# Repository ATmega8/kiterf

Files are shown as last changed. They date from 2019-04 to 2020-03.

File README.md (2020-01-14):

# _KiteRF_





_KiteRF is a SDR system with K210 & FPGA & ESP32 as its core controller, which make SDR more intelligent, portable and cheap._

* KiteRF Structure

  KiteRF

  * DS (Digital Signal) unit

    * FPGA (Field-Programmable Gate Array)

      * Radio Frequency Data Processing

      * DS Control

      * Communication with PC

    * K210 (Kendryte K210)

      * LCD control

      * Camera control

      * Audio

      * FFT

    * ESP32 (Espressif ESP32)

      * Wi-Fi Data Transmission

      * SDCARD control

      * Touch Button

      * RGB LED Control

  * RF (Radio Frequency) unit

    * ADC (Analog-to-Digital Converter)
    
      * Sampling Analog Baseband IQ Data

    * DAC (Digital-to-Analog Converter)

      * Output Analog Baseband IQ Data 

    * RF Transceiver

      * Mixing IF signal to baseband and outputting IQ analog signal

    * VCO (Voltage-Controlled Oscillator)

      * Provide local IF frequency

    * Mixer (Frequency mixer)

      * Mixing HF signal to IF signal

    * LNA (Low-Noise Amplifier)

      * Suppression of Mirror Noise Signal

    * RF Switch

      * Switching signal paths in different frequencies

* KiteRF core-board v1.0.0

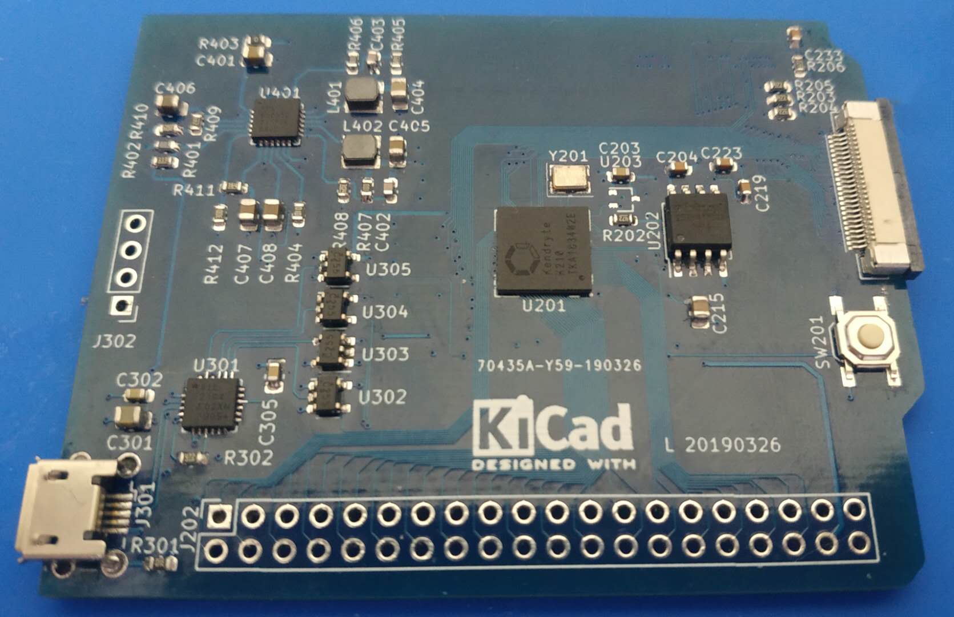
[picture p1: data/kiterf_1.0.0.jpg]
KiteRF
  

## Contents



* Directory tree

    ```
    ├── add_path.sh
    ├── data
    │   ├── kendryte_datasheet.pdf
    │   ├── kendryte_freertos_programming_guide.pdf
    │   ├── kiterf_1.0.0.jpg
    │   ├── kiterf_structure.pos
    │   └── kiterf_structure.svg
    ├── docs
    │   └── Doxyfile
    ├── LICENSE
    ├── project
    │   ├── code
    │   │   ├── ESP32
    │   │   ├── ESP8266
    │   │   └── K210
    │   └── pcb
    │       ├── K210
    │       └── RF
    ├── README.md
    └── tools
        ├── cmake-3.14.2
        ├── ESP32
        │   └── esp-idf
        ├── ESP8266
        │   ├── ESP8266_RTOS_SDK
        │   └── xtensa-lx106-elf
        └── K210
            ├── kendryte-freertos-sdk
            ├── kendryte-toolchain
            └── kflash
    ```

    * project

      * PCB project (KiCAD)

      * FPGA project (ISE)

      * ESP32 project (esp-idf)

      * K210 project (Kendryte FreeRTOS)

    * release

      * PCB Gerber

      * FPGA bin

      * ESP32 bin

      * K210 bin

    * tools

      * script

      * SDK

      * toolchain

## How to use

You can follow the steps below to set up the development environment, or directly download the release version of the full environment.

* clone

  ```bash
  git clone --recursive https://github.com/ATmega8/kiterf
  cd kiterf
  ```

  * note

    Don't omit `--recursive`, because we use submodule.

* update

  ```bash
  git pull
  git submodule update --init --recursive
  ```

* Add environment variables

  ```bash
  . add_path.sh
  ```
  * note

    Don't forget `"."`

* Install toolchain

  * K210

    * Ubuntu/Debian/Kali

      ```bash
      wget https://www.kiterf.xyz/download/kendryte-toolchain-ubuntu-amd64-8.2.0-20190213.tar.gz
      tar zxvf kendryte-toolchain-ubuntu-amd64-8.2.0-20190213.tar.gz -C tools/K210/
      rm kendryte-toolchain-ubuntu-amd64-8.2.0-20190213.tar.gz
      ```
    
    * Arch

      ```bash
      wget https://www.kiterf.xyz/download/kendryte-toolchain-arch-amd64-8.2.0-20190415.tar.gz
      tar zxvf kendryte-toolchain-arch-amd64-8.2.0-20190415.tar.gz -C tools/K210/
      rm kendryte-toolchain-arch-amd64-8.2.0-20190415.tar.gz
      ```

  * ESP32

    * Ubuntu/Debian/Kali/Arch

      ```bash
      cd tools/ESP32/esp-idf
      ./install.sh
      cd $KITERF_PATH
      ```

  * ESP8266

    KiteRF also integrates the ESP8266 development environment, which is not necessary, and you can choose to ignore it.

    * Ubuntu/Debian/Kali/Arch

      ```bash
      wget https://www.kiterf.xyz/download/xtensa-lx106-elf-linux64-1.22.0-92-g8facf4c-5.2.0.tar.gz
      tar zxvf xtensa-lx106-elf-linux64-1.22.0-92-g8facf4c-5.2.0.tar.gz -C tools/ESP8266/
      rm xtensa-lx106-elf-linux64-1.22.0-92-g8facf4c-5.2.0.tar.gz
      ```

  * CMake

    * Ubuntu/Debian/Kali/Arch

      ```bash
      wget https://www.kiterf.xyz/download/cmake-3.14.2.tar.gz
      tar xf cmake-3.14.2.tar.gz -C tools/
      cd tools/cmake-3.14.2
      ./configure
      # Please do not use all CPU cores to compile, otherwise your computer may crash.
      make -j2
      cd $KITERF_PATH
      rm cmake-3.14.2.tar.gz
      ```

## Release

* download

  ```bash
  wget https://www.kiterf.xyz/download/kiterf-debain-amd64-1.2.0-20190517.tar.gz
  tar zxvf kiterf-debain-amd64-1.2.0-20190517.tar.gz
  rm kiterf-debain-amd64-1.2.0-20190517.tar.gz
  cd kiterf
  ```
* Add environment variables

  ```bash
  . add_path.sh
  ```
  * note

    Don't forget `"."`

## License



* MIT License
 
  A short and simple permissive license with conditions only requiring preservation of copyright and license notices. Licensed works, modifications, and larger works may be distributed under different terms and without source code.

## Contributing



If you want to support this project, we hope you can contribute your code or circuit.

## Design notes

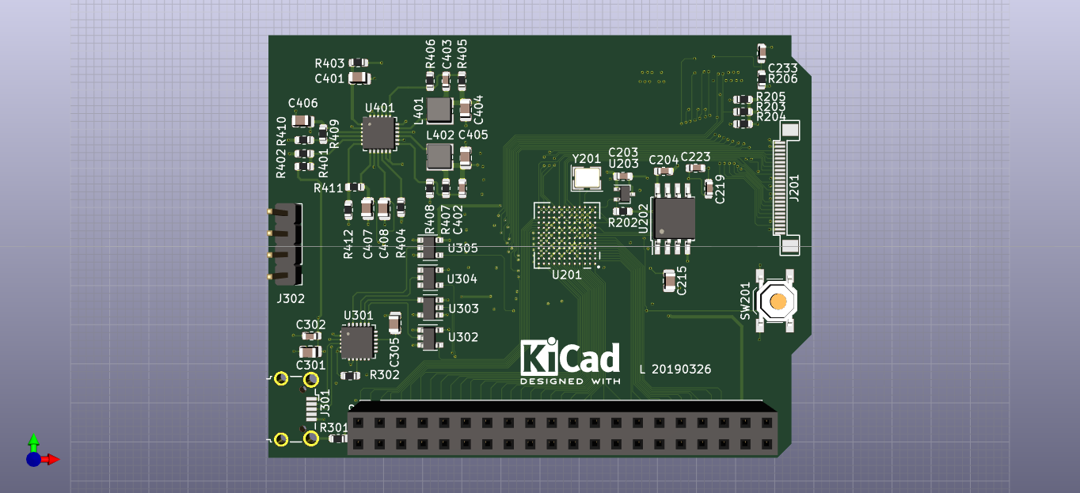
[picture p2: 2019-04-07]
project/pcb/K210/ESP32_K210.png

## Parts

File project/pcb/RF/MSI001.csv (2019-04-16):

Source: | /home/life/Code/kiterf/project/pcb/RF/MSI001.sch
Date: | 2019年04月16日 星期二 14时15分33秒
Tool: | Eeschema 5.1.0
Generator: | /usr/share/kicad/plugins/bom_csv_grouped_by_value_with_fp.py
Component Count: | 170
Ref | Qnty | Value | Cmp name | Footprint | Description | Vendor
C205, C206, C207, C208, C210, C212, C209, C211, C217, C215, C204, C202, C213, C214, C303, C313, | 16 | 0.1uF | C | Capacitor_SMD:C_0603_1608Metric | Unpolarized capacitor
C216, C203, C201, C508, C507, C503, C505, C509, | 8 | 10uF | C | Capacitor_SMD:C_0805_2012Metric | Unpolarized capacitor
C304, C306, | 2 | 100pF | C | Capacitor_SMD:C_0603_1608Metric | Unpolarized capacitor
C310, C326, | 2 | 3.3pF | C | Capacitor_SMD:C_0603_1608Metric | Unpolarized capacitor
C311, C302, | 2 | 120pF | C | Capacitor_SMD:C_0603_1608Metric | Unpolarized capacitor
C312, C322, C323, C324, | 4 | 1000pF | C | Capacitor_SMD:C_0603_1608Metric | Unpolarized capacitor
C314, | 1 | 82pF | C | Capacitor_SMD:C_0603_1608Metric | Unpolarized capacitor
C315, C328, | 2 | 2.7pF | C | Capacitor_SMD:C_0603_1608Metric | Unpolarized capacitor
C320, | 1 | 180pF | C | Capacitor_SMD:C_0603_1608Metric | Unpolarized capacitor
C321, | 1 | 3.9pF | C | Capacitor_SMD:C_0603_1608Metric | Unpolarized capacitor
C327, | 1 | 12pF | C | Capacitor_SMD:C_0603_1608Metric | Unpolarized capacitor
C402, C404, C401, C403, | 4 | 5.6pF | C | Capacitor_SMD:C_0603_1608Metric | Unpolarized capacitor
C405, C329, | 2 | 4.7pF | C | Capacitor_SMD:C_0603_1608Metric | Unpolarized capacitor
C406, C408, | 2 | 27pF | C | Capacitor_SMD:C_0603_1608Metric | Unpolarized capacitor
C409, C420, | 2 | 10pF | C | Capacitor_SMD:C_0603_1608Metric | Unpolarized capacitor
C410, C501, C502, | 3 | 22pF | C | Capacitor_SMD:C_0603_1608Metric | Unpolarized capacitor
C411, | 1 | 1nF | C | Capacitor_SMD:C_0603_1608Metric | Unpolarized capacitor
C412, C416, C407, | 3 | 1.8pF | C | Capacitor_SMD:C_0603_1608Metric | Unpolarized capacitor
C414, C316, C325, C301, | 4 | 39pF | C | Capacitor_SMD:C_0603_1608Metric | Unpolarized capacitor
C415, C419, C423, C424, C425, C422, C421, C429, C433, C436, C430, C428, C431, C432, C504, C506, C307, C305, C309, C308, C332, C330, C331, C318, C319, C317, | 26 | 10nF | C | Capacitor_SMD:C_0603_1608Metric | Unpolarized capacitor
C417, | 1 | 2.2pF | C | Capacitor_SMD:C_0603_1608Metric | Unpolarized capacitor
C418, C413, | 2 | 1.5pF | C | Capacitor_SMD:C_0603_1608Metric | Unpolarized capacitor
C426, C427, | 2 | 100nF | C | Capacitor_SMD:C_0603_1608Metric | Unpolarized capacitor
C434, | 1 | 6800pF | C | Capacitor_SMD:C_0603_1608Metric | Unpolarized capacitor
C435, | 1 | 33nF | C | Capacitor_SMD:C_0603_1608Metric | Unpolarized capacitor
C511, C510, C512, | 3 | 1uF | C | Capacitor_SMD:C_0805_2012Metric | Unpolarized capacitor
FB502, FB501, FB503, | 3 | Ferrite_Bead | Ferrite_Bead | Inductor_SMD:L_0805_2012Metric | Ferrite bead
J101, | 1 | CONTROL | Conn_02x08_Odd_Even | Connector_PinSocket_2.54mm:PinSocket_2x08_P2.54mm_Vertical | Generic connector, double row, 02x08, odd/even pin numbering scheme (row 1 odd numbers, row 2 even numbers), script generated (kicad-library-utils/schlib/autogen/connector/)
J201, | 1 | Conn_02x12_Odd_Even | Conn_02x12_Odd_Even | Connector_PinSocket_2.54mm:PinSocket_2x12_P2.54mm_Vertical | Generic connector, double row, 02x12, odd/even pin numbering scheme (row 1 odd numbers, row 2 even numbers), script generated (kicad-library-utils/schlib/autogen/connector/)
J301, | 1 | ANT | Conn_Coaxial | Connector_Coaxial:SMA_Amphenol_132289_EdgeMount | coaxial connector (BNC, SMA, SMB, SMC, Cinch/RCA, ...)
J501, | 1 | +5V | Conn_01x02_Female | Connector_PinSocket_2.54mm:PinSocket_1x02_P2.54mm_Vertical | Generic connector, single row, 01x02, script generated (kicad-library-utils/schlib/autogen/connector/)
JP201, | 1 | Jumper_NC_Dual | Jumper_NC_Dual | Jumper:SolderJumper-3_P1.3mm_Open_Pad1.0x1.5mm | Dual jumper, normally closed
JP202, | 1 | SolderJumper_3_Open | SolderJumper_3_Open | Jumper:SolderJumper-3_P1.3mm_Open_RoundedPad1.0x1.5mm | Solder Jumper, 3-pole, open
L301, | 1 | 150nH | L | Inductor_SMD:L_0603_1608Metric | Inductor
L302, | 1 | 390nH | L | Inductor_SMD:L_0603_1608Metric | Inductor
L303, | 1 | 1uH | L | Inductor_SMD:L_0603_1608Metric | Inductor
L304, L307, | 2 | 330nH | L | Inductor_SMD:L_0603_1608Metric | Inductor
L305, | 1 | 470nH | L | Inductor_SMD:L_0603_1608Metric | Inductor
L306, | 1 | 220nH | L | Inductor_SMD:L_0603_1608Metric | Inductor
L309, | 1 | 120nH | L | Inductor_SMD:L_0603_1608Metric | Inductor
L401, L310, | 2 | 82nH | L | Inductor_SMD:L_0603_1608Metric | Inductor
L402, | 1 | 15nH | L | Inductor_SMD:L_0603_1608Metric | Inductor
L403, | 1 | 68nH | L | Inductor_SMD:L_0603_1608Metric | Inductor
L404, | 1 | 22nH | L | Inductor_SMD:L_0603_1608Metric | Inductor
L405, | 1 | 33nH | L | Inductor_SMD:L_0603_1608Metric | Inductor
L407, | 1 | 39nH | L | Inductor_SMD:L_0603_1608Metric | Inductor
L408, | 1 | 6.8pF | L | Inductor_SMD:L_0603_1608Metric | Inductor
L409, | 1 | 6.8nH | L | Inductor_SMD:L_0603_1608Metric | Inductor
L410, L308, | 2 | 47nH | L | Inductor_SMD:L_0603_1608Metric | Inductor
L411, L406, | 2 | 100nH | L | Inductor_SMD:L_0603_1608Metric | Inductor
L412, | 1 | 270nH | L | Inductor_SMD:L_0603_1608Metric | Inductor
L413, | 1 | 8.2nH | L | Inductor_SMD:L_0603_1608Metric | Inductor
Q301, Q302, | 2 | DMG1016 | Q_PMOS_DGS | Package_TO_SOT_SMD:SOT-23 | P-MOSFET transistor, drain/gate/source
R202, R203, R204, R201, | 4 | 36R | R | Resistor_SMD:R_0603_1608Metric | Resistor
R205, R206, R207, R208, R209, R210, R506, R504, R505, R503, | 10 | 0R | R | Resistor_SMD:R_0603_1608Metric | Resistor
R301, | 1 | 270R | R | Resistor_SMD:R_0603_1608Metric | Resistor
R302, | 1 | 100K | R | Resistor_SMD:R_0603_1608Metric | Resistor
R402, R406, R401, R405, | 4 | 33R | R | Resistor_SMD:R_0603_1608Metric | Resistor
R404, R403, | 2 | 18R | R | Resistor_SMD:R_0603_1608Metric | Resistor
R407, | 1 | 390 | R | Resistor_SMD:R_0603_1608Metric | Resistor
R502, R501, | 2 | 10K | R | Resistor_SMD:R_0603_1608Metric | Resistor
U202, U201, | 2 | 74LVC1G125 | 74LVC1G125 | Package_TO_SOT_SMD:SOT-23-5 | Single Buffer Gate Tri-State, Low-Voltage CMOS
U203, | 1 | AD9288 | AD9288 | Package_QFP:LQFP-48_7x7mm_P0.5mm
U301, U305, | 2 | PE42641 | PE42641 | Package_DFN_QFN:QFN-16-1EP_3x3mm_P0.5mm_EP1.7x1.7mm
U302, | 1 | MGA68563 | MGA68563 | Package_TO_SOT_SMD:SOT-363_SC-70-6
U303, | 1 | 74LVC1G08 | 74LVC1G08 | Package_TO_SOT_SMD:SOT-23-5 | Single AND Gate, Low-Voltage CMOS
U304, | 1 | SKY13251 | SKY13251 | Package_DFN_QFN:DFN-8-1EP_2x2mm_P0.5mm_EP0.9x1.3mm
U401, | 1 | MSI001 | MSI001 | Package_DFN_QFN:QFN-40-1EP_6x6mm_P0.5mm_EP4.6x4.6mm_ThermalVias
U501, | 1 | SI5351A | SI5351A | Package_SO:MSOP-10_3x3mm_P0.5mm
U503, U502, | 2 | LP5907MFX-3.3 | LP5907MFX-2.8 | Package_TO_SOT_SMD:SOT-23-5 | 250-mA Ultra-Low-Noise Low-IQ LDO, 2.8V, SOT-23
U504, | 1 | LP5907MFX-2.8 | LP5907MFX-2.8 | Package_TO_SOT_SMD:SOT-23-5 | 250-mA Ultra-Low-Noise Low-IQ LDO, 2.8V, SOT-23
Y501, | 1 | 25MHz 10ppm | Crystal_GND24_Small | Crystal:Crystal_SMD_3225-4Pin_3.2x2.5mm | Four pin crystal, GND on pins 2 and 4, small symbol

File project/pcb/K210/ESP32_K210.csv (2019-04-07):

Source: | /home/life/KICAD/ESP32_K210/ESP32_K210.sch
Date: | 2019年03月26日 星期二 02时06分47秒
Tool: | Eeschema 5.1.0
Generator: | /usr/share/kicad/plugins/bom_csv_grouped_by_value_with_fp.py
Component Count: | 90
Ref | Qnty | Value | Cmp name | Footprint | Description | Vendor
C201, C202, | 2 | 10p | C | Capacitor_SMD:C_0603_1608Metric | Unpolarized capacitor
C204, C203, C229, C232, C206, C207, C209, C210, C211, C212, C213, C216, C217, C218, C219, C221, C223, C225, C227, C224, C226, C228, | 22 | 0.1uF | C | Capacitor_SMD:C_0603_1608Metric | Unpolarized capacitor
C205, C208, C215, C214, C222, C220, C303, C305, C301, | 9 | 4.7uF | C-SmartRelay-rescue | Capacitor_SMD:C_0805_2012Metric
C230, C231, | 2 | 4.7uF | C | Capacitor_SMD:C_0603_1608Metric | Unpolarized capacitor
C233, | 1 | 1uF | C | Capacitor_SMD:C_0603_1608Metric | Unpolarized capacitor
C304, C302, | 2 | 0.1u | C-SmartRelay-rescue | Capacitor_SMD:C_0603_1608Metric
C401, | 1 | 1u | C | Capacitor_SMD:C_0805_2012Metric | Unpolarized capacitor
C403, C402, | 2 | 47p | C | Capacitor_SMD:C_0603_1608Metric | Unpolarized capacitor
C404, | 1 | 10u | C | Capacitor_SMD:C_0805_2012Metric | Unpolarized capacitor
C405, | 1 | 10uF | C | Capacitor_SMD:C_0805_2012Metric | Unpolarized capacitor
C406, C407, C408, | 3 | 4.7u | C | Capacitor_SMD:C_0805_2012Metric | Unpolarized capacitor
FB203, FB201, FB202, | 3 | 600R@100MHz | Ferrite_Bead_Small | Inductor_SMD:L_0805_2012Metric | Ferrite bead, small symbol
J201, | 1 | Camera | Conn_01x24 | FPC:FPC_24 | Generic connector, single row, 01x24, script generated (kicad-library-utils/schlib/autogen/connector/)
J202, | 1 | Conn_02x20_Odd_Even | Conn_02x20_Odd_Even | Connector_PinSocket_2.54mm:PinSocket_2x20_P2.54mm_Vertical | Generic connector, double row, 02x20, odd/even pin numbering scheme (row 1 odd numbers, row 2 even numbers), script generated (kicad-library-utils/schlib/autogen/connector/)
J203, | 1 | LCD | Conn_2Rows-45Pins | FPC:FH26-xxS-0.3SHW | Generic connector, double row, 45 pins, odd/even pin numbering scheme (row 1 odd numbers, row 2 even numbers), script generated (kicad-library-utils/schlib/autogen/connector/)
J301, | 1 | USB_OTG | USB_OTG-SmartRelay-rescue | Connector_USB:USB_Micro-B_Wuerth_629105150521_CircularHoles
J302, | 1 | Conn_01x04 | Conn_01x04-SmartRelay-rescue | Connector_PinHeader_2.54mm:PinHeader_1x04_P2.54mm_Vertical
JP201, | 1 | IO18-IO35 | SolderJumper_3_Open | Jumper:SolderJumper-3_P1.3mm_Open_RoundedPad1.0x1.5mm | Solder Jumper, 3-pole, open
JP202, | 1 | IO0-IO17 | SolderJumper_3_Open | Jumper:SolderJumper-3_P1.3mm_Open_RoundedPad1.0x1.5mm | Solder Jumper, 3-pole, open
JP203, | 1 | IO36-IO47 | SolderJumper_3_Open | Jumper:SolderJumper-3_P1.3mm_Open_RoundedPad1.0x1.5mm | Solder Jumper, 3-pole, open
L401, | 1 | 3.3uH | L | Inductor_SMD:L_Wuerth_MAPI-3015 | Inductor
L402, | 1 | 2.2uH | L | Inductor_SMD:L_Wuerth_MAPI-3010 | Inductor
R201, R301, | 2 | 1M | R-SmartRelay-rescue | Resistor_SMD:R_0603_1608Metric
R202, R206, R404, | 3 | 100K | R | Resistor_SMD:R_0603_1608Metric | Resistor
R203, R204, R205, | 3 | 10K | R | Resistor_SMD:R_0603_1608Metric | Resistor
R302, | 1 | 4K7 | R-SmartRelay-rescue | Resistor_SMD:R_0603_1608Metric
R401, | 1 | 33K | R | Resistor_SMD:R_0603_1608Metric | Resistor
R402, | 1 | 68K | R | Resistor_SMD:R_0603_1608Metric | Resistor
R403, | 1 | 1R | R | Resistor_SMD:R_0603_1608Metric | Resistor
R405, | 1 | 680K | R | Resistor_SMD:R_0603_1608Metric | Resistor
R406, R407, | 2 | 150K | R | Resistor_SMD:R_0603_1608Metric | Resistor
R408, R410, | 2 | 300K | R | Resistor_SMD:R_0603_1608Metric | Resistor
R409, | 1 | 240K | R | Resistor_SMD:R_0603_1608Metric | Resistor
R411, | 1 | 360K | R | Resistor_SMD:R_0603_1608Metric | Resistor
R412, | 1 | 200K | R | Resistor_SMD:R_0603_1608Metric | Resistor
SW201, | 1 | RESET | SW_Push | Button_Switch_SMD:SW_SPST_TL3342 | Push button switch, generic, two pins
U201, | 1 | K210 | K210 | k210:BGA-144_12x12_8.0x8.0mm
U202, | 1 | W25Q64FW | W25Q32 | Package_SO:SOIJ-8_5.3x5.3mm_P1.27mm
U203, | 1 | MAX803 | MAX803 | Package_TO_SOT_SMD:SOT-323_SC-70
U301, | 1 | CP2104 | CP2104-SmartRelay-rescue | Package_DFN_QFN:QFN-24-1EP_4x4mm_P0.5mm_EP2.7x2.6mm_ThermalVias
U305, U302, U304, U303, | 4 | 74LVC1G125 | 74LVC1G125 | Package_TO_SOT_SMD:SOT-23-5 | Single Buffer Gate Tri-State, Low-Voltage CMOS
U401, | 1 | TPS650532 | TPS65053 | Package_DFN_QFN:QFN-24-1EP_4x4mm_P0.5mm_EP2.7x2.6mm_ThermalVias
Y201, | 1 | 26MHz 10ppm | Crystal_GND24_Small | Crystal:Crystal_SMD_3225-4Pin_3.2x2.5mm | Four pin crystal, GND on pins 2 and 4, small symbol

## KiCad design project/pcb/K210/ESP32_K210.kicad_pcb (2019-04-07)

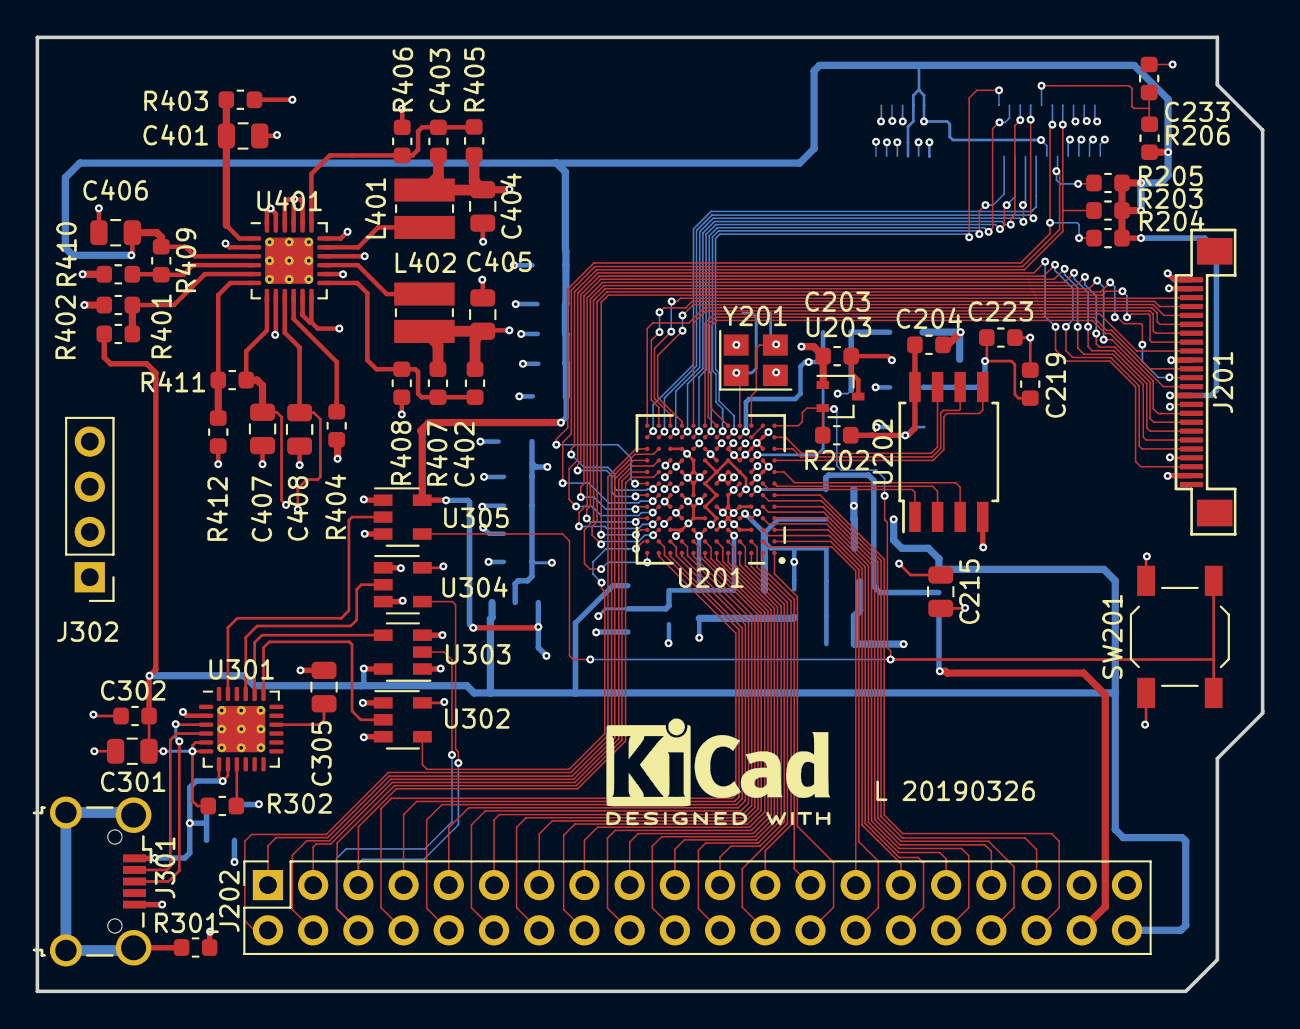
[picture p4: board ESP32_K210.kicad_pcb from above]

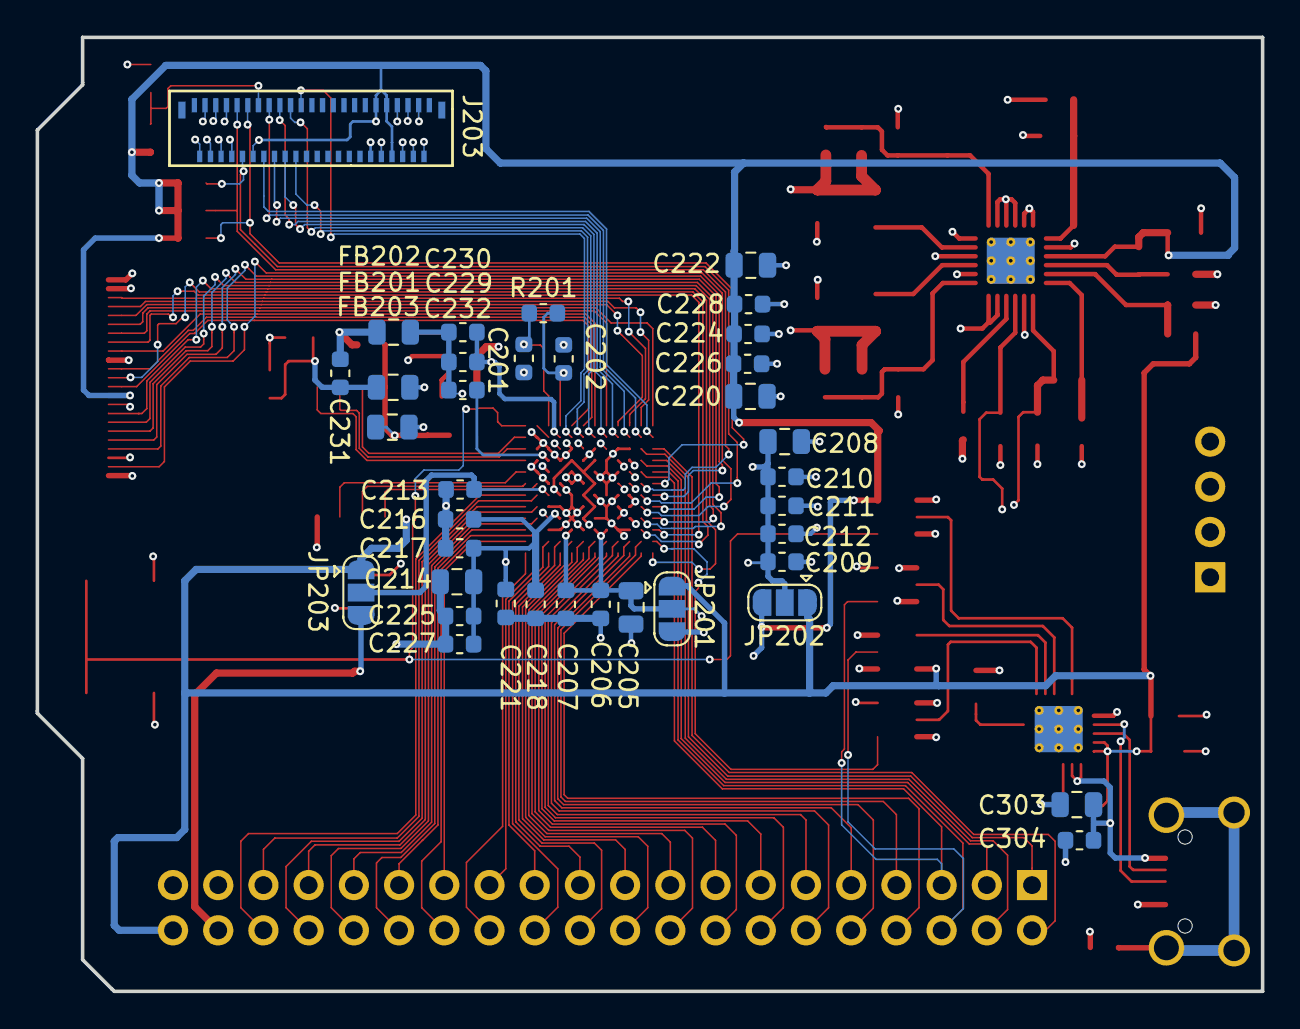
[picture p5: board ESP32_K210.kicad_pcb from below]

Board: 4 copper layers, 68.8 x 53.6 mm, 90 parts (37 on the bottom side), 106 nets.

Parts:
C201, C202: 10p; C_0603_1608Metric
C203, C204, C206, C207, C209, C210, C211, C212, C213, C216, C217, C218, C219, C221, C223, C224, C225, C226, C227, C228, C229, C232: 0.1uF; C_0603_1608Metric
C205, C208, C214, C215, C220, C222, C301, C303, C305: 4.7uF; C_0805_2012Metric
C230, C231: 4.7uF; C_0603_1608Metric
C233: 1uF; C_0603_1608Metric
C302, C304: 0.1u; C_0603_1608Metric
C401: 1u; C_0805_2012Metric
C402, C403: 47p; C_0603_1608Metric
C404: 10u; C_0805_2012Metric
C405: 10uF; C_0805_2012Metric
C406, C407, C408: 4.7u; C_0805_2012Metric
FB201, FB202, FB203: 600R@100MHz; L_0805_2012Metric
J201: Camera; FPC_24
J202: Conn_02x20_Odd_Even; PinSocket_2x20_P2.54mm_Vertical
J203: LCD; FH26-xxS-0.3SHW
J301: USB_OTG; USB_Micro-B_Wuerth_629105150521_CircularHoles
J302: Conn_01x04; PinHeader_1x04_P2.54mm_Vertical
JP201: IO18-IO35; SolderJumper-3_P1.3mm_Open_RoundedPad1.0x1.5mm
JP202: IO0-IO17; SolderJumper-3_P1.3mm_Open_RoundedPad1.0x1.5mm
JP203: IO36-IO47; SolderJumper-3_P1.3mm_Open_RoundedPad1.0x1.5mm
L401: 3.3uH; L_Wuerth_MAPI-3015
L402: 2.2uH; L_Wuerth_MAPI-3010
R201, R301: 1M; R_0603_1608Metric
R202, R206, R404: 100K; R_0603_1608Metric
R203, R204, R205: 10K; R_0603_1608Metric
R302: 4K7; R_0603_1608Metric
R401: 33K; R_0603_1608Metric
R402: 68K; R_0603_1608Metric
R403: 1R; R_0603_1608Metric
R405: 680K; R_0603_1608Metric
R406, R407: 150K; R_0603_1608Metric
R408, R410: 300K; R_0603_1608Metric
R409: 240K; R_0603_1608Metric
R411: 360K; R_0603_1608Metric
R412: 200K; R_0603_1608Metric
SW201: RESET; SW_SPST_TL3342
U201: K210; BGA-144_12x12_8.0x8.0mm
U202: W25Q64FW; SOIJ-8_5.3x5.3mm_P1.27mm
U203: MAX803; SOT-323_SC-70
U301: CP2104; QFN-24-1EP_4x4mm_P0.5mm_EP2.7x2.6mm_ThermalVias
U302, U303, U304, U305: 74LVC1G125; SOT-23-5
U401: TPS650532; QFN-24-1EP_4x4mm_P0.5mm_EP2.7x2.6mm_ThermalVias
Y201: 26MHz 10ppm; Crystal_SMD_3225-4Pin_3.2x2.5mm

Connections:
+1V5: C408.1, J201.10, U401.9
+1V8: C204.1, C220.1, C222.1, C224.1, C226.1, C228.1, C406.1, FB203.1, J201.11, J202.38, J203.8, J203.9, J203.11, J203.34, JP201.3, JP202.3, JP203.3, R202.1, R203.1, R204.1, R205.1, R206.1, R409.1, U201.H3, U201.K6, U201.K8, U202.8, U305.5, U401.3
+2V8: C407.1, J201.4, R411.1, U401.7
+3V3: C203.1, C301.1, C302.1, C403.1, C404.1, J201.23, J202.40, J203.12, J203.44, JP201.1, JP202.1, JP203.1, L401.2, R302.1, R401.1, R405.1, U203.3, U301.5, U301.6, U302.5
+5V: C303.1, C304.1, J301.1, J302.1, J302.2, R403.2, R404.2, U301.7, U301.8, U401.2, U401.8, U401.11, U401.12, U401.16, U401.20, U401.21, U401.22
/K210/BOOT: U201.B12, U303.4
/K210/DB0: J203.32, U201.L12
/K210/DB1: J203.31, U201.L11
/K210/DB2: J203.30, U201.L10
/K210/DB3: J203.29, U201.L9
/K210/DB4: J203.28, U201.L8
/K210/DB5: J203.27, U201.L7
/K210/DB6: J203.26, U201.L6
/K210/DB7: J203.25, U201.L5
/K210/DVP-HREF: J201.9, U201.A12
/K210/DVP-PCLK: J201.17, U201.C12
/K210/DVP-PWDN: J201.8, U201.D12
/K210/DVP-RESET: J201.6, U201.E12
/K210/DVP-SIO_C: J201.5, U201.F12
/K210/DVP-SIO_D: J201.3, U201.E11
/K210/DVP-VSYNC: J201.7, U201.D11
/K210/DVP-XCLK: J201.13, U201.C11
/K210/DVP-Y2: J201.19, U201.M12
/K210/DVP-Y3: J201.21, U201.M11
/K210/DVP-Y4: J201.22, U201.M10
/K210/DVP-Y5: J201.20, U201.M9
/K210/DVP-Y6: J201.18, U201.M8
/K210/DVP-Y7: J201.16, U201.M7
/K210/DVP-Y8: J201.14, U201.M6
/K210/DVP-Y9: J201.12, U201.M5
/K210/FLASH_CLK: U201.K1, U202.6
/K210/FLASH_CS: U201.G2, U202.1
/K210/FLASH_D0: U201.J1, U202.5
/K210/FLASH_D1: U201.G1, U202.2
/K210/FLASH_D2: U201.H1, U202.3
/K210/FLASH_D3: U201.L1, U202.7
/K210/IO0: J202.1, U201.K11
/K210/IO1: J202.2, U201.K12
/K210/IO2: J202.3, U201.J11
/K210/IO3: J202.4, U201.J12
/K210/IO4: J202.5, U201.H11, U304.4
/K210/IO5: J202.6, U201.H12, U302.2
/K210/IO18: J202.7, U201.B11
/K210/IO19: J202.8, U201.A11
/K210/IO20: J202.9, U201.B10
/K210/IO21: J202.10, U201.A10
/K210/IO22: J202.11, U201.B9
/K210/IO23: J202.12, U201.A9
/K210/IO24: J202.13, U201.B8
/K210/IO25: J202.14, U201.A8
/K210/IO26: J202.15, U201.B7
/K210/IO27: J202.16, U201.A7
/K210/IO28: J202.17, U201.B6
/K210/IO29: J202.18, U201.A6
/K210/IO30: J202.19, U201.B5
/K210/IO31: J202.20, U201.A5
/K210/IO32: J202.21, U201.B4
/K210/IO33: J202.22, U201.A4
/K210/IO34: J202.23, U201.B3
/K210/IO35: J202.24, U201.A3
/K210/IO36: J202.25, U201.A2
/K210/IO37: J202.26, U201.A1
/K210/IO38: J202.27, U201.B2
/K210/IO39: J202.28, U201.B1
/K210/IO40: J202.29, U201.C2
/K210/IO41: J202.30, U201.C1
/K210/IO42: J202.31, U201.D2
/K210/IO43: J202.32, U201.D1
/K210/IO44: J202.33, U201.E2
/K210/IO45: J202.34, U201.E1
/K210/IO46: J202.35, U201.F2
/K210/IO47: J202.36, U201.F1
/K210/LCD-CS: J203.37, R203.2, U201.G11
/K210/LCD-DC: J203.36, R205.2, U201.F11
/K210/LCD-WR: J203.35, R204.2, U201.G12
/K210/RESET: R202.2, SW201.2, U201.M1, U203.2, U305.4
/K210/USB2UART/DTR: U301.23, U305.2
/K210/USB2UART/RTS: U301.19, U303.2
/K210/USB2UART/RXD: U301.20, U302.4
/K210/USB2UART/TXD: U301.21, U304.2
/K210/USB2UART/USB_D+: J301.3, U301.3
/K210/USB2UART/USB_D-: J301.2, U301.4
/K210/VB012: C205.1, C206.1, C207.1, JP201.2, U201.C5, U201.C7, U201.C8, U303.5, U304.5
/K210/VB67: C213.1, JP203.2, U201.D3, U201.F3
/K210/VB345: C208.1, C209.1, C210.1, C211.1, C212.1, JP202.2, U201.D10, U201.G10, U201.H10
GND: C201.2, C202.2, C203.2, C204.2, C205.2, C206.2, C207.2, C208.2, C209.2, C210.2, C211.2, C212.2, C213.2, C214.2, C215.2, C216.2, C217.2, C218.2, C219.2, C220.2, C221.2, C222.2, C223.2, C224.2, C225.2, C226.2, C227.2, C228.2, C231.2, C233.2, C301.2, C302.2, C303.2, C304.2, C305.2, C401.2, C404.2, C405.2, C406.2, C407.2, C408.2, FB202.1, J201.2, J201.15, J201.24, J202.37, J202.39, J203.2, J203.3, J203.4, J203.5, J203.6, J203.7, J203.10, J203.38, J203.39, J203.40, J203.41, J203.42, J203.43, J301.5, J302.3, J302.4, R301.2, R402.2, R406.2, R408.2, R410.2, R412.2, SW201.1, U201.C3, U201.C4, U201.C6, U201.C9, U201.C10, U201.D5, U201.D7, U201.D8, U201.E3, U201.E4, U201.E5, U201.E6, U201.E8, U201.E10, U201.F5, U201.F7, U201.F8, U201.F9, U201.F10, U201.G3, U201.G4, U201.G5, U201.G6, U201.G8, U201.H2, U201.H5, U201.H7, U201.H8, U201.H9, U201.J2, U201.J4, U201.J6, U201.J8, U201.J10, U201.K2, U201.K3, U201.K5, U201.K7, U201.K9, U201.K10, U201.L2, U202.4, U203.1, U301.2, U301.25, U302.1, U302.3, U303.1, U303.3, U304.1, U304.3, U305.1, U305.3, U401.14, U401.18, U401.23, U401.24, Y201.2, Y201.4
unnamed: C201.1, R201.2, U201.M4, Y201.1
unnamed: C202.1, R201.1, U201.M3, Y201.3
unnamed: C229.1, C230.1, FB201.2, U201.L4
unnamed: C229.2, C230.2, C232.2, FB202.2, U201.K4
unnamed: C232.1, FB203.2, U201.J3
unnamed: C233.1, J203.33, R206.2
unnamed: C305.1, U301.16
unnamed: C401.1, R403.1, U401.1
unnamed: C402.2, R407.2, R408.1, U401.13
unnamed: C403.2, R405.2, R406.1, U401.19
unnamed: J301.6, R301.1
unnamed: L401.1, U401.17
unnamed: L402.1, U401.15
unnamed: R302.2, U301.9
unnamed: R401.2, R402.1, U401.5
unnamed: R404.1, U401.10
unnamed: R409.2, R410.1, U401.4
unnamed: R411.2, R412.1, U401.6
unnamed: U201.L3, U201.M2
VCC: C214.1, C215.1, C216.1, C217.1, C218.1, C219.1, C221.1, C223.1, C225.1, C227.1, C231.1, C402.1, C405.1, FB201.1, L402.2, R407.1, U201.D4, U201.D6, U201.D9, U201.E7, U201.E9, U201.F4, U201.F6, U201.G7, U201.G9, U201.H4, U201.H6, U201.J5, U201.J7, U201.J9

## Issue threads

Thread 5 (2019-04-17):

矩阵运算错误

xiongyumail, 2019-04-17:
### 当前
使用<https://github.com/ATmega8/mmo>库测试结果如下
MMO Test:

ESP32 Fail

K210 Fail->Pass

### 需求
需要有一个新的稳定矩阵运算库/算法

xiongyumail, 2019-04-18:
ESP32 Fail->Pass

Closed 2019-04-18.

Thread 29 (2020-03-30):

ESP32+FPGA板需求

ATmega8, 2020-03-30:
希望在此issue下大家能讨论下ESP32+FPGA需要实现的功能。FPAG暂定ice40up5k。 @xiongyumail @wangxian0718 @TreeNewbeer @zhuanyanchengkong

xiongyumail, 2020-03-31:
大project

ATmega8, 2020-04-01:
https://github.com/TreeNewbeer/Coonix

Closed 2020-04-01.

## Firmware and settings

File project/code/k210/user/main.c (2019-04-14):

/* Copyright 2018 Canaan Inc.
 *
 * Licensed under the Apache License, Version 2.0 (the "License");
 * you may not use this file except in compliance with the License.
 * You may obtain a copy of the License at
 *
 *     http://www.apache.org/licenses/LICENSE-2.0
 *
 * Unless required by applicable law or agreed to in writing, software
 * distributed under the License is distributed on an "AS IS" BASIS,
 * WITHOUT WARRANTIES OR CONDITIONS OF ANY KIND, either express or implied.
 * See the License for the specific language governing permissions and
 * limitations under the License.
 */
#include <stdio.h>
#include <stdlib.h>
#include <stdio.h>
#include <time.h>
#include <sys/time.h>
#include <math.h>
#include "encoding.h"
#include "devices.h"
#include "FreeRTOS.h"
#include "task.h"
#include "fft_soft.h"

#define FFT_N               512U
/**
 * FFT 16-bit registers lead to data overflow (-32768-32767),
 * FFT has nine layers, shift determines which layer needs shift operation to prevent overflow.
 * (for example, 0x1ff means 9 layers do shift operation; 0x03 means the first layer and the second layer do shift operation) 
 * If shifted, the result is different from the normal FFT.
 */
#define FFT_FORWARD_SHIFT   0x0U
#define FFT_BACKWARD_SHIFT  0x1ffU
#define PI                  3.14159265358979323846

typedef struct _complex_hard
{
    int16_t real;
    int16_t imag;
} complex_hard_t;

enum _complex_mode
{
    FFT_HARD = 0,
    FFT_SOFT = 1,
    FFT_COMPLEX_MAX,
} ;
    
enum _time_get
{
    TEST_START = 0,
    TEST_STOP = 1,
    TEST_TIME_MAX,
} ;

int16_t real[FFT_N];
int16_t imag[FFT_N];
float hard_power[FFT_N];
float soft_power[FFT_N];
float hard_angel[FFT_N];
float soft_angel[FFT_N];
uint64_t fft_out_data[FFT_N / 2];
uint64_t buffer_input[FFT_N];
uint64_t buffer_output[FFT_N];
struct timeval get_time[FFT_COMPLEX_MAX][FFT_DIR_MAX][TEST_TIME_MAX];

uint16_t get_bit1_num(uint32_t data)
{
    uint16_t num;
    for (num = 0; data; num++)
        data &= data - 1;
    return num;
}

void test_task(void *arg)
{
    uint32_t cnt = 0;
    while (1) {
        printf("hello kiterf! Count: %d\n", cnt++);
        vTaskDelay(500 / portTICK_RATE_MS);
    }
    vTaskDelete(NULL);
}

int main()
{
    int32_t i;
    float tempf1[3];
    fft_data_t *output_data;
    fft_data_t *input_data;
    uint16_t bit1_num = get_bit1_num(FFT_FORWARD_SHIFT);
    complex_hard_t data_hard[FFT_N] = {0};
    complex data_soft[FFT_N] = {0};

    /* Data prepared for fft hard calculation and fft soft calculation. */
    for (i = 0; i < FFT_N; i++)
    {
        tempf1[0] = 0.3 * cosf(2 * PI * i / FFT_N + PI / 3) * 256;
        tempf1[1] = 0.1 * cosf(16 * 2 * PI * i / FFT_N - PI / 9) * 256;
        tempf1[2] = 0.5 * cosf((19 * 2 * PI * i / FFT_N) + PI / 6) * 256;
        data_hard[i].real = (int16_t)(tempf1[0] + tempf1[1] + tempf1[2] + 10);
        data_hard[i].imag = (int16_t)0;
        data_soft[i].real = data_hard[i].real;
        data_soft[i].imag = data_hard[i].imag;
    }

    /* Data format conversion for hard fft module. */
    for (int i = 0; i < FFT_N / 2; ++i)
    {
        input_data = (fft_data_t *)&buffer_input[i];
        input_data->R1 = data_hard[2 * i].real;
        input_data->I1 = data_hard[2 * i].imag;
        input_data->R2 = data_hard[2 * i + 1].real;
        input_data->I2 = data_hard[2 * i + 1].imag;
    }

    /* FFT hard calculation. */
    gettimeofday(&get_time[FFT_HARD][FFT_DIR_FORWARD][TEST_START], NULL);
    fft_complex_uint16(FFT_FORWARD_SHIFT, FFT_DIR_FORWARD, buffer_input, FFT_N, buffer_output);
    gettimeofday(&get_time[FFT_HARD][FFT_DIR_FORWARD][TEST_STOP], NULL);

    /* FFT soft calculation. */
    gettimeofday(&get_time[FFT_SOFT][FFT_DIR_FORWARD][TEST_START], NULL);
    fft_soft(data_soft, FFT_N);
    gettimeofday(&get_time[FFT_SOFT][FFT_DIR_FORWARD][TEST_STOP], NULL);

    /* Data format conversion get from hard fft module output. */
    for (i = 0; i < FFT_N / 2; i++)
    {
        output_data = (fft_data_t*)&buffer_output[i];
        data_hard[2 * i].imag = output_data->I1 ;
        data_hard[2 * i].real = output_data->R1 ;
        data_hard[2 * i + 1].imag = output_data->I2 ;
        data_hard[2 * i + 1].real = output_data->R2 ;
    }

    /* Compare the difference between hardware fft and software fft calculation. */
    printf("\n[hard fft real][soft fft real][hard fft imag][soft fft imag]\n");
    for (i = 0; i < FFT_N / 2; i++)
        printf("%3d:%7d %7d %7d %7d\n",
                i, data_hard[i].real, (int32_t)data_soft[i].real, data_hard[i].imag, (int32_t)data_soft[i].imag);

    /* Power calculation. */
    for (i = 0; i < FFT_N; i++)
    {
        hard_power[i] = sqrt(data_hard[i].real * data_hard[i].real + data_hard[i].imag * data_hard[i].imag) * 2;
        soft_power[i] = sqrt(data_soft[i].real * data_soft[i].real + data_soft[i].imag * data_soft[i].imag) * 2;
    }
    printf("\nhard power  soft power:\n");
    printf("%3d : %f  %f\n", 0, hard_power[0] / 2 / FFT_N * (1 << bit1_num), soft_power[0] / 2 / FFT_N);
    for (i = 1; i < FFT_N / 2; i++)
        printf("%3d : %f  %f\n", i, hard_power[i] / FFT_N * (1 << bit1_num), soft_power[i] / FFT_N);

    printf("\nhard phase  soft phase:\n");
    for (i = 0; i < FFT_N / 2; i++)
    {
        hard_angel[i] = atan2(data_hard[i].imag, data_hard[i].real);
        soft_angel[i] = atan2(data_soft[i].imag, data_soft[i].real);
        printf("%3d : %f  %f\n", i, hard_angel[i] * 180 / PI, soft_angel[i] * 180 / PI);
    }

    for (int i = 0; i < FFT_N / 2; ++i)
    {
        input_data = (fft_data_t *)&buffer_input[i];
        input_data->R1 = data_hard[2 * i].real;
        input_data->I1 = data_hard[2 * i].imag;
        input_data->R2 = data_hard[2 * i + 1].real;
        input_data->I2 = data_hard[2 * i + 1].imag;
    }

    /* IFFT hard calculation. */
    gettimeofday(&get_time[FFT_HARD][FFT_DIR_BACKWARD][TEST_START], NULL);
    fft_complex_uint16(FFT_BACKWARD_SHIFT, FFT_DIR_BACKWARD, buffer_input, FFT_N, buffer_output);
    gettimeofday(&get_time[FFT_HARD][FFT_DIR_BACKWARD][TEST_STOP], NULL);

    /* IFFT soft calculation. */
    gettimeofday(&get_time[FFT_SOFT][FFT_DIR_BACKWARD][TEST_START], NULL);
    ifft_soft(data_soft, FFT_N);
    gettimeofday(&get_time[FFT_SOFT][FFT_DIR_BACKWARD][TEST_STOP], NULL);

    /* Data format conversion get from hard fft module output. */
    for (i = 0; i < FFT_N / 2; i++)
    {
        output_data = (fft_data_t*)&buffer_output[i];
        data_hard[2 * i].imag = output_data->I1 ;
        data_hard[2 * i].real = output_data->R1 ;
        data_hard[2 * i + 1].imag = output_data->I2 ;
        data_hard[2 * i + 1].real = output_data->R2 ;
    }

    /* Compare the difference between hardware ifft and software ifft calculation. */
    printf("\n[hard ifft real][soft ifft real][hard ifft imag][soft ifft imag]\n");
    for (i = 0; i < FFT_N / 2; i++)
        printf("%3d:%7d  %7d %7d %7d\n",
            i, data_hard[i].real, (int32_t)data_soft[i].real, data_hard[i].imag, (int32_t)data_soft[i].imag);

    /* Compare time. */
    printf("[hard ][%d bytes][forward time = %ld us][backward time = %ld us]\n",
            FFT_N,
            ((get_time[FFT_HARD][FFT_DIR_FORWARD][TEST_STOP].tv_sec -get_time[FFT_HARD][FFT_DIR_FORWARD][TEST_START].tv_sec) * 1000*1000 +
            (get_time[FFT_HARD][FFT_DIR_FORWARD][TEST_STOP].tv_usec - get_time[FFT_HARD][FFT_DIR_FORWARD][TEST_START].tv_usec)),
            ((get_time[FFT_HARD][FFT_DIR_BACKWARD][TEST_STOP].tv_sec -get_time[FFT_HARD][FFT_DIR_BACKWARD][TEST_START].tv_sec) * 1000*1000 +
            (get_time[FFT_HARD][FFT_DIR_BACKWARD][TEST_STOP].tv_usec - get_time[FFT_HARD][FFT_DIR_BACKWARD][TEST_START].tv_usec)));
    printf("[soft ][%d bytes][forward time = %ld us][backward time = %ld us]\n",
            FFT_N,
            (get_time[FFT_SOFT][FFT_DIR_FORWARD][TEST_STOP].tv_sec -get_time[FFT_SOFT][FFT_DIR_FORWARD][TEST_START].tv_sec) * 1000*1000 +
            (get_time[FFT_SOFT][FFT_DIR_FORWARD][TEST_STOP].tv_usec - get_time[FFT_SOFT][FFT_DIR_FORWARD][TEST_START].tv_usec),
            (get_time[FFT_SOFT][FFT_DIR_BACKWARD][TEST_STOP].tv_sec -get_time[FFT_SOFT][FFT_DIR_BACKWARD][TEST_START].tv_sec) * 1000*1000 +
            (get_time[FFT_SOFT][FFT_DIR_BACKWARD][TEST_STOP].tv_usec - get_time[FFT_SOFT][FFT_DIR_BACKWARD][TEST_START].tv_usec));

    xTaskCreate(test_task, "test_task", 1024, NULL, 5, NULL);

    while (1);
    return 0;
}

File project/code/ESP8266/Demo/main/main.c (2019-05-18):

#include <stdio.h>
#include <stdlib.h>
#include <stdio.h>
#include <time.h>
#include <sys/time.h>
#include <math.h>
#include "freertos/FreeRTOS.h"
#include "freertos/task.h"
#include "freertos/semphr.h"
#include "esp_system.h"
#include "esp_log.h"
#include "fft_soft.h"
#include "matrix.h"
#include "test.h"
#include "unity.h"
#include "dsp_math.h"
#include "lvgl.h"

#define FFT_N               512U
#define FFT_FORWARD_SHIFT   0x0U
#define FFT_BACKWARD_SHIFT  0x1ffU
#define PI                  3.14159265358979323846

enum _complex_mode {
    FFT_SOFT = 0,
    FFT_COMPLEX_MAX,
} ;

enum _fft_direction {
    FFT_DIR_BACKWARD = 0,
    FFT_DIR_FORWARD,
    FFT_DIR_MAX,
} ;

enum _time_get {
    TEST_START = 0,
    TEST_STOP = 1,
    TEST_TIME_MAX,
} ;

float soft_power[FFT_N];
float soft_angel[FFT_N];
struct timeval get_time[FFT_COMPLEX_MAX][FFT_DIR_MAX][TEST_TIME_MAX];

SemaphoreHandle_t matrix_sem = NULL;
SemaphoreHandle_t dsp_sem = NULL;

void fft_task(void *arg)
{
    int32_t i;
    float tempf1[3];
    complex data_soft[FFT_N] = {0};

    printf("~~~~~~~~~~~~~~~~~~~~~~~~~~~~\n");

    /* Data prepared for fft hard calculation and fft soft calculation. */
    for (i = 0; i < FFT_N; i++) {
        tempf1[0] = 0.3 * cosf(2 * PI * i / FFT_N + PI / 3) * 256;
        tempf1[1] = 0.1 * cosf(16 * 2 * PI * i / FFT_N - PI / 9) * 256;
        tempf1[2] = 0.5 * cosf((19 * 2 * PI * i / FFT_N) + PI / 6) * 256;
        data_soft[i].real = (int16_t)(tempf1[0] + tempf1[1] + tempf1[2] + 10);
        data_soft[i].imag = (int16_t)0;
    }

    /* FFT soft calculation. */
    gettimeofday(&get_time[FFT_SOFT][FFT_DIR_FORWARD][TEST_START], NULL);
    fft_soft(data_soft, FFT_N);
    gettimeofday(&get_time[FFT_SOFT][FFT_DIR_FORWARD][TEST_STOP], NULL);

    printf("\n[soft fft real][soft fft imag]\n");

    for (i = 0; i < FFT_N / 2; i++)
        printf("%3d:%7d %7d\n",
               i, (int32_t)data_soft[i].real, (int32_t)data_soft[i].imag);

    /* Power calculation. */
    for (i = 0; i < FFT_N; i++) {
        soft_power[i] = sqrt(data_soft[i].real * data_soft[i].real + data_soft[i].imag * data_soft[i].imag) * 2;
    }

    printf("\nsoft power:\n");
    printf("%3d : %f\n", 0, soft_power[0] / 2 / FFT_N);

    for (i = 1; i < FFT_N / 2; i++) {
        printf("%3d : %f\n", i, soft_power[i] / FFT_N);
    }

    printf("\nsoft phase:\n");

    for (i = 0; i < FFT_N / 2; i++) {
        soft_angel[i] = atan2(data_soft[i].imag, data_soft[i].real);
        printf("%3d : %f\n", i, soft_angel[i] * 180 / PI);
    }

    /* IFFT soft calculation. */
    gettimeofday(&get_time[FFT_SOFT][FFT_DIR_BACKWARD][TEST_START], NULL);
    ifft_soft(data_soft, FFT_N);
    gettimeofday(&get_time[FFT_SOFT][FFT_DIR_BACKWARD][TEST_STOP], NULL);

    printf("\n[soft ifft real][soft ifft imag]\n");

    for (i = 0; i < FFT_N / 2; i++)
        printf("%3d:%7d %7d\n",
               i, (int32_t)data_soft[i].real, (int32_t)data_soft[i].imag);

    printf("[soft ][%d bytes][forward time = %ld us][backward time = %ld us]\n",
           FFT_N,
           (get_time[FFT_SOFT][FFT_DIR_FORWARD][TEST_STOP].tv_sec - get_time[FFT_SOFT][FFT_DIR_FORWARD][TEST_START].tv_sec) * 1000 * 1000 +
           (get_time[FFT_SOFT][FFT_DIR_FORWARD][TEST_STOP].tv_usec - get_time[FFT_SOFT][FFT_DIR_FORWARD][TEST_START].tv_usec),
           (get_time[FFT_SOFT][FFT_DIR_BACKWARD][TEST_STOP].tv_sec - get_time[FFT_SOFT][FFT_DIR_BACKWARD][TEST_START].tv_sec) * 1000 * 1000 +
           (get_time[FFT_SOFT][FFT_DIR_BACKWARD][TEST_STOP].tv_usec - get_time[FFT_SOFT][FFT_DIR_BACKWARD][TEST_START].tv_usec));
    xSemaphoreGive(matrix_sem);

    vTaskSuspend(NULL);
}

void matrix_task(void *arg)
{
    xSemaphoreTake(matrix_sem, portMAX_DELAY);
    printf("~~~~~~~~~~~~~~~~~~~~~~~~~~~~\n");
    UnityBegin("matrix test");
    RunMatrixTest();
    RunMatrixAddTest();
    RunMatrixSubTest();
    RunMatrixMulTest();
    RunMatrixInvTest();
    UnityEnd();
    xSemaphoreGive(dsp_sem);

    vTaskSuspend(NULL);
}

static float cof[38] = {-0.00028361, -0.00075393, -0.00109268, -0.0006769, 0.00102914, 0.00391172, \
                        0.00678037, 0.0074884, 0.00382395, -0.00503141, -0.0171363, -0.02737452, \
                        -0.02859017, -0.01418401, 0.01873238, 0.0670341, 0.12139937, 0.16869521, \
                        0.19622892, 0.19622892, 0.16869521, 0.12139937, 0.0670341, 0.01873238, \
                        -0.01418401, -0.02859017, -0.0273745, -0.0171363, -0.00503141, 0.00382395, \
                        0.0074884, 0.00678037, 0.00391172, 0.00102914, -0.0006769, -0.00109268, \
                        -0.00075393, -0.00028361
                        };

static float x_data[64] = {1.1016856340840009, 1.3819116564898124, 1.2902960763808005, 1.0566626343732346,
                           0.9442254510513154, 0.9579868821695956, 1.046306253339488, 1.2410366852938386,
                           1.4436282176750759, 1.3874515506551908, 1.0378805602935988, 0.7756155443385301,
                           0.9178050511383941, 1.2537702552749763, 1.3426204627941956, 1.117610065929717,
                           0.8800604905211858, 0.8012517778630224, 0.7821389128510301, 0.7711632039505969,
                           0.8501510692896972, 0.951564312477108, 0.8436661347816815, 0.5268377902750552,
                           0.33441324855963317, 0.4608704807237677, 0.660838911589431, 0.6315802275119023,
                           0.4503064294285132, 0.3690546542314113, 0.3830365542353578, 0.32286699253190193,
                           0.23477111445056748, 0.30990336758188164, 0.4885556520187167, 0.49487230610275945,
                           0.29017088466245566, 0.15479252877059746, 0.24169920785325388, 0.3670607943691402,
                           0.36701157780354643, 0.3520189111198753, 0.42271529556318366, 0.4225052367712395,
                           0.23092439222513883, 0.06926710273608785, 0.1994021343386783, 0.4723172130423151,
                           0.5111771910438687, 0.2622959422441363, 0.03179207010391415, 0.00435686084990973,
                           0.060746245121383116, 0.09208186182560787, 0.14769880330463428, 0.18278609616995745,
                           0.004175541124054452, -0.36016119316009115, -0.5430364808518742, -0.33032288155563755,
                           -0.031070289589745434, -0.0789812885502211, -0.444599870929681, -0.7399276026332652
                           };
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

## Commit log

2019-04-07 Init commit
    [ESP32_K210.csv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]
2019-04-07 feature(README): add icons
    [ESP32_K210.csv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]
2019-04-10 feature(project): update structure
    [ADC.sch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]
2019-04-10 feature(pcb/RF): update RF part schematic
    [ADC.sch, Filter.sch, MSI.sch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]
2019-04-14 feature(pcb/RF): finished RF part schematic
    [ADC.sch, Filter.sch, MSI.sch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]
2019-04-14 feature(esp32): add esp32 environment
2019-04-16 feature(pcb/RF): update RF part BOM
    [MSI001.csv]
2019-04-17 bugfix(PCB): fixed symbol libraries path.
2019-04-18 feature(fir) add fir function from arm dsp library
2019-04-20 feature(ring_buf): add ESP32&K210 ring_buf
2019-04-20 feature(dsp): add ESP32&K210 dsp lib
2019-04-21 feature(pid): add ESP32&K210 pid library
2019-05-10 feature(pcb/rf) fix some bug
2019-05-10 bugfix(code/K210)增加build.sh可执行权限
2019-05-12 feature(ESP32): add ESP32 lcd demo
2019-07-08 bugfix(ram): fix buffer size error
    [lcd.c, main.c]
2019-07-08 wifi and spiffs ok
    [partitions.csv]
2019-07-10 encoder ok
2020-01-14 clean project
    [partitions.csv]
2020-01-14 feature(ESP32): add lua
2020-03-01 add lcd hx8357 driver
2020-03-01 lcd_write_data 增加空指针判断
